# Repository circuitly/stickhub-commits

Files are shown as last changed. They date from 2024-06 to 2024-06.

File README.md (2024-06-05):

# StickHub

By Stefan Hamminga
https://rbts.co
See LICENSE.md for license details

The Space Friendly 7-Port USB 2 Hub - KiCAD design files

A tiny (16.5 x 40mm) USB 2.0 hub with 7 ports for connecting lots of USB devices to, for example, a Raspberry Pi or Jetson board. Each port uses a JST SH 1.0mm pitch connector, making a hub assembly far more compact and lightweight than possible with regular USB plugs.

In contrast to cheap hubs each port supports LS, FS and HS independently for optimal performance of all devices. Power is taken from the upstream port by default, but removing the fuse (or replacing it by a diode) allows using external 5V supply.

Full ESD protection: A TVS per data line and a 2012 capacitor per power line. Inrush current control and short circuit protection. 308uF downstream capacitance. Individual status LEDs for the downsteam ports.

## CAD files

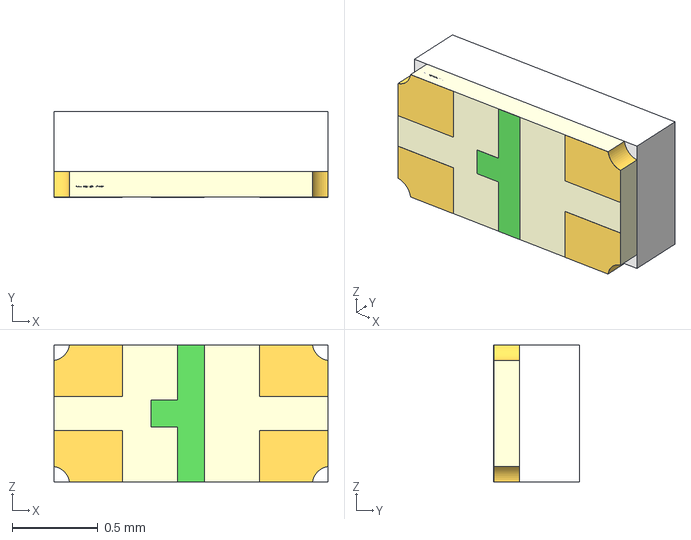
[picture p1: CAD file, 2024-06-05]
3dmodels/APHB1608.step
1.60 x 0.501 x 0.8 mm

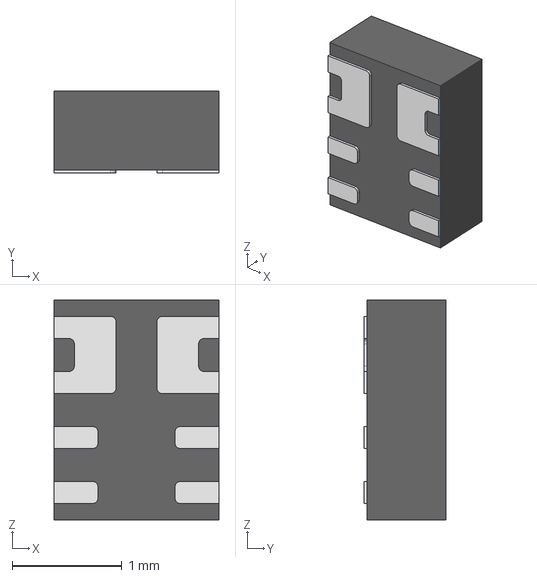
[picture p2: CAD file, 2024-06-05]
3dmodels/TDFN-8_1.5x2mm_Fused-Lead_MO-252-W2015D.step
1.50 x 0.75 x 2.00 mm

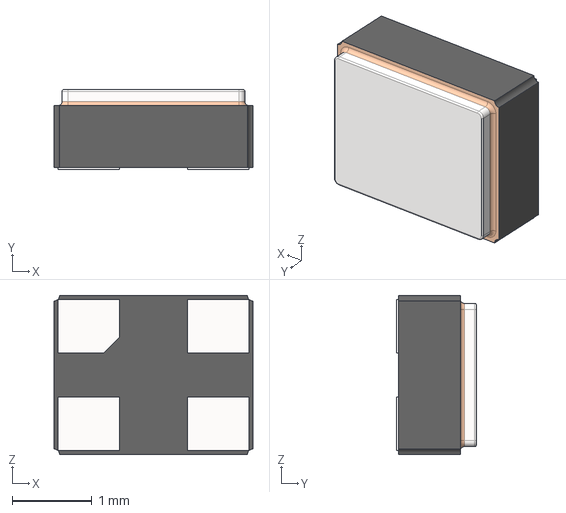
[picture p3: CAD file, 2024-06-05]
3dmodels/Crystal_SMD_4P_2520.step
2.50 x 1.00 x 2.00 mm

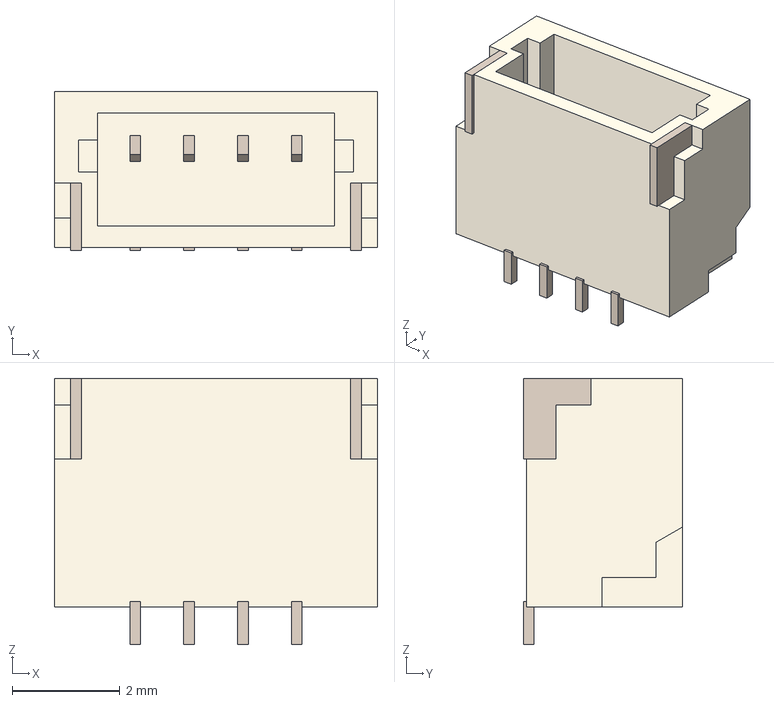
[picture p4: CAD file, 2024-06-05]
3dmodels/JST_SH_SM04B-SRSS-TB.STEP
6.00 x 2.96 x 4.95 mm

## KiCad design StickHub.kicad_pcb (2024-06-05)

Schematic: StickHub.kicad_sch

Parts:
C1: 1uF 10V; 1608_C; Voltage 16V; Tolerance 10%; MPN FS15B105K100PKG
C2, C5, C6, C7, C8, C9, C10, C11, C12, C13: 0.1uF; 1608_C; Voltage 16V; Tolerance 10%; MPN CC0402KRX7R7BB104
C3, C4: 10uF 6.3V; 1608_C; Voltage 16V; Tolerance 10%; MPN CL05A106MQ5NUNC
C14, C15, C16, C17, C18, C19, C20, C21: 0.1uF 100V; 1608_C; Voltage 16V; Tolerance 10%; MPN NM0805B104K101CEDN
C22, C23, C24, C25, C26, C27, C29, C30, C31, C32, C33, C34, C35, C36, C37: 22uF 10V; 1608_C; Voltage 16V; Tolerance 10%; MPN GRM188R61A226ME15D
C28: 15nF; 1608_C; Voltage 16V; Tolerance 10%
C38: 330uF 10V; CP_Elec_6.3x7.7
D1, D2, D3, D4, D5, D6, D7, D8, D9, D10, D11, D12, D13, D14, D22, D23: TVS; 1006_C; MPN AR0521P1
D15, D16, D17, D18, D19, D20, D21: USB; Duo_LED_1.6x0.8_Kingbright_APHB1608LZGKSURKC; MPN APHB1608SGEC
D24, D25: 5V; 1006_C; MPN D5V0H1B2LP-7B
H1: Strap; Plain_Hole_3mm
J1: HOST; USB_A_PCB_traces_small
J2: USB1; JST_SH_SM04B-SRSS-TB_1x04-1MP_P1.00mm_Horizontal; MPN SM04B-SRSS-TB(LF)(SN)
J3: USB2; JST_SH_SM04B-SRSS-TB_1x04-1MP_P1.00mm_Horizontal; MPN SM04B-SRSS-TB(LF)(SN)
J4: USB3; JST_SH_SM04B-SRSS-TB_1x04-1MP_P1.00mm_Horizontal; MPN SM04B-SRSS-TB(LF)(SN)
J5: USB4; JST_SH_SM04B-SRSS-TB_1x04-1MP_P1.00mm_Horizontal; MPN SM04B-SRSS-TB(LF)(SN)
J6: USB5; JST_SH_SM04B-SRSS-TB_1x04-1MP_P1.00mm_Horizontal; MPN SM04B-SRSS-TB(LF)(SN)
J7: USB6; JST_SH_SM04B-SRSS-TB_1x04-1MP_P1.00mm_Horizontal; MPN SM04B-SRSS-TB(LF)(SN)
J8: USB7; JST_SH_SM04B-SRSS-TB_1x04-1MP_P1.00mm_Horizontal; MPN SM04B-SRSS-TB(LF)(SN)
J9: EXTGND; 1P-1.5x1.5
JP1: EXTPWR; PinHeader_1x02_P2.54mm_Vertical
LOGO1, LOGO2, LOGO3, LOGO4: Logo
R1: 10k; 1608_C; MPN 0402WGF1002TCE
R2, R3, R4, R5: 100k; 1608_C; MPN 0402WGF1003TCE
R6: 2.7k; 1608_C; MPN 0402WGF2701TCE
R7, R8, R9, R10, R11, R12, R13: 470; 1608_C; MPN 0402WGF4700TCE
U1: MaxLinear_XR22417-48; LQFP-48_7x7mm_P0.5mm; MPN XR22417CV48TR-F
U2: Dialog_SLG5NT1487V; TDFN-8_1.5x2mm_Fused-Lead_JEDEC_MO-252_W2015D; MPN SLG5NT1487VTR
Y1: 12MHz 50ppm 16-20pF; Crystal_4-SMD_2.5x2mm; MPN CM4012M00020T8188026

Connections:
+1V8: C4.1, C11.1, C12.1, C13.1, U1.6 (VCC18), U1.21 (VCC18), U1.25 (1V8_OUT), U1.28 (VCC18)
+3.3V: C3.1, C5.1, C6.1, C7.1, C8.1, C9.1, C10.1, R3.1, R4.1, R5.1, U1.9 (3V3_OUT), U1.15 (VCC33), U1.20 (VCC33), U1.26 (VCC33), U1.31 (VCC33), U1.36 (VCC33), U1.42 (VCC33)
+5V: C1.1, C14.1, C15.1, C16.1, C17.1, C18.1, C19.1, C20.1, C22.1, C23.1, C24.1, C25.1, C26.1, C27.1, C29.1, C30.1, C31.1, C32.1, C33.1, C34.1, C35.1, C36.1, C37.1, C38.1 (+), D25.2 (A2), J2.1, J3.1, J4.1, J5.1, J6.1, J7.1, J8.1, R1.1, U1.8 (VCC5), U2.5 (S)
/D+: D23.2 (A2), J1.3, U1.30 (UP_D+)
/D-: D22.2 (A2), J1.2, U1.29 (UP_D-)
/LC: D15.GK (2), D15.RA (3), D16.GK (2), D16.RA (3), D17.GK (2), D17.RA (3), D18.GK (2), D18.RA (3), D19.GK (2), D19.RA (3), D20.GK (2), D20.RA (3), D21.GK (2), D21.RA (3), U1.1 (LED_CTL)
/LED1: R7.2, U1.3 (LED1/SCL)
/LED2: R8.2, U1.4 (LED2)
/LED3: R9.2, U1.5 (LED3)
/LED4: R10.2, U1.7 (LED4)
/LED5: R11.2, U1.48 (LED5)
/LED6: R12.2, U1.47 (LED6)
/LED7: R13.2, U1.46 (LED7)
/U1D+: D2.2 (A2), J2.3, U1.19 (USB1D+)
/U1D-: D1.2 (A2), J2.2, U1.18 (USB1D-)
/U2D+: D4.2 (A2), J3.3, U1.17 (USB2D+)
/U2D-: D3.2 (A2), J3.2, U1.16 (USB2D-)
/U3D+: D6.2 (A2), J4.3, U1.14 (USB3D+)
/U3D-: D5.2 (A2), J4.2, U1.13 (USB3D-)
/U4D+: D8.2 (A2), J5.3, U1.12 (USB4D+)
/U4D-: D7.2 (A2), J5.2, U1.11 (USB4D-)
/U5D+: D10.2 (A2), J6.3, U1.33 (USB5D+)
/U5D-: D9.2 (A2), J6.2, U1.32 (USB5D-)
/U6D+: D12.2 (A2), J7.3, U1.35 (USB6D+)
/U6D-: D11.2 (A2), J7.2, U1.34 (USB6D-)
/U7D+: D14.2 (A2), J8.3, U1.38 (USB7D+)
/U7D-: D13.2 (A2), J8.2, U1.37 (USB7D-)
/XI: U1.22 (XTALIN), Y1.1
/XO: U1.23 (XTALOUT), Y1.3
GND: C1.2, C2.2, C3.2, C4.2, C5.2, C6.2, C7.2, C8.2, C9.2, C10.2, C11.2, C12.2, C13.2, C14.2, C15.2, C16.2, C17.2, C18.2, C19.2, C20.2, C21.2, C22.2, C23.2, C24.2, C25.2, C26.2, C27.2, C28.2, C29.2, C30.2, C31.2, C32.2, C33.2, C34.2, C35.2, C36.2, C37.2, C38.2 (-), D1.1 (A1), D2.1 (A1), D3.1 (A1), D4.1 (A1), D5.1 (A1), D6.1 (A1), D7.1 (A1), D8.1 (A1), D9.1 (A1), D10.1 (A1), D11.1 (A1), D12.1 (A1), D13.1 (A1), D14.1 (A1), D22.1 (A1), D23.1 (A1), D24.1 (A1), D25.1 (A1), J1.4, J2.4, J2.MP (MountPin), J3.4, J3.MP (MountPin), J4.4, J4.MP (MountPin), J5.4, J5.MP (MountPin), J6.4, J6.MP (MountPin), J7.4, J7.MP (MountPin), J8.4, J8.MP (MountPin), J9.1, R2.2, R6.2, U1.10 (GND), U1.24 (GND), U1.39 (GND), U2.8 (GND), Y1.2 (GND), Y1.4 (GND)
unnamed: D15.GA (1), D15.RK (4), R7.1
unnamed: D16.GA (1), D16.RK (4), R8.1
unnamed: D17.GA (1), D17.RK (4), R9.1
unnamed: D18.GA (1), D18.RK (4), R10.1
unnamed: D19.GA (1), D19.RK (4), R11.1
unnamed: D20.GA (1), D20.RK (4), R12.1
unnamed: D21.GA (1), D21.RK (4), R13.1
unnamed: J1.1, JP1.1
unnamed: R3.2, U1.40 (EXT_RST#)
unnamed: R6.1, U1.27 (REXT)
unnamed: R5.2, U1.43 (TEST1#)
unnamed: R4.2, U1.45 (TEST3#)
unnamed: C2.1, R1.2, R2.1, U1.41 (VBUS_SENSE)
unnamed: C28.1, U2.7 (CAP)
VIN: C21.1, D24.2 (A2), JP1.2, U2.1 (VDD), U2.2 (ON), U2.3 (D)

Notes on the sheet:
ESD caps at connectors / plug
Shared VBUS capacitance

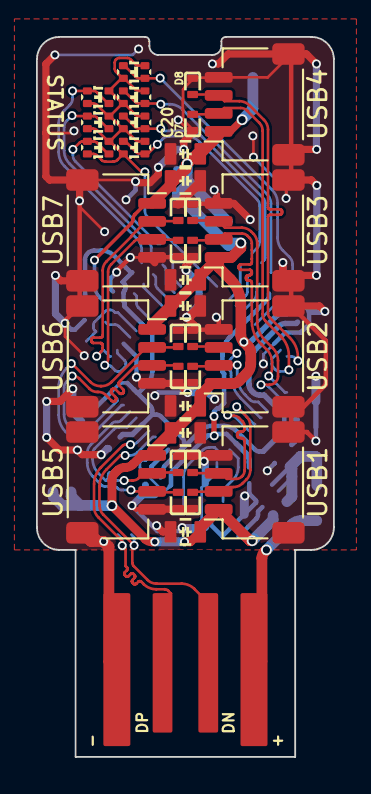
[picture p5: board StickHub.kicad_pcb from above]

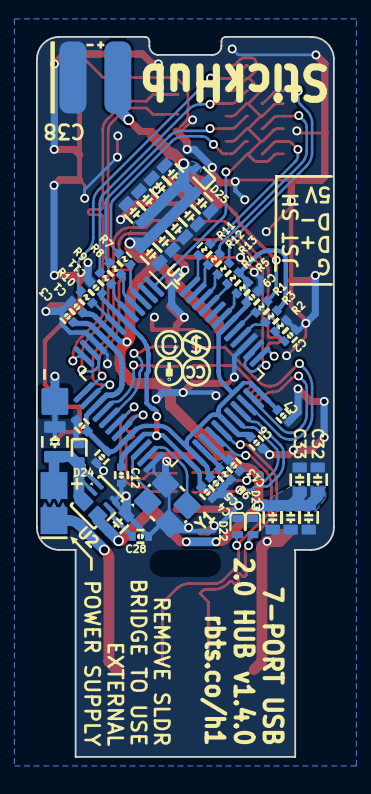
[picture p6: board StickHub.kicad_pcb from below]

Board: 2 copper layers, 16.5 x 40.0 mm, 94 parts (57 on the bottom side), 45 nets.

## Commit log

2024-06-05 Initial commit.
    [APHB1608.step, Crystal_SMD_4P_2520.step, JST_SH_SM04B-SRSS-TB.STEP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]
2024-06-05 Removing chunks of schematic and board.
    [StickHub.kicad_pcb, StickHub.kicad_sch]
2024-06-05 Revert "Removing chunks of schematic and board."
    This reverts commit 6f6bff356a7eff26be86b812d608cab446a31a50.
    [StickHub.kicad_pcb, StickHub.kicad_sch]
2024-06-05 Changing capacitor values.
    [StickHub.kicad_sch]
